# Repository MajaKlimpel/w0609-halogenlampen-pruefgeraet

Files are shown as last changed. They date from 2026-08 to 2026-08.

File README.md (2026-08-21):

# W0609 Halogenlampen-Prüfgerät

Prüfgerät für Lebensdauertests an Halogenlampen mit zehn parallel betriebenen Kanälen.

Entstanden im Rahmen der Bachelorarbeit "Konzeption, Entwicklung und Validierung eines
automatisierten Prüfgeräts zur parallelen Prüfung von Halogenlampen" von Maja Klimpel,
Technische Universität Berlin, Fachgebiet Elektronische Mess- und Diagnosetechnik,
in Zusammenarbeit mit der KNAUER Wissenschaftliche Geräte GmbH, 2026.

## Überblick

Halogenlampen werden bei KNAUER als Lichtquellen in HPLC-Detektoren eingesetzt.
Mit dem entwickelten Prüfgerät können bis zu zehn Lampen gleichzeitig unter definierten
Bedingungen getestet werden. Dazu werden wiederkehrende Schaltzyklen mit Anstiegsrampe,
Haltephase, Abwärtsrampe und Abkühlphase durchgeführt. Während des Tests werden Strom
und Spannung jedes Kanals, sechs Temperaturen und die Lüfterdrehzahlen sekündlich
erfasst und gespeichert. Sinkt der Strom eines Kanals während der Haltephase unter
0,5 A, wird die entsprechende Lampe als ausgefallen erkannt. Der betroffene Kanal wird
daraufhin abgeschaltet und der Ausfall zusammen mit der Zyklusnummer gespeichert.

Das System besteht aus zwei Teilen. Auf einem Teensy 4.1 läuft die Firmware, die die
Ausgangsspannungen regelt, den Testablauf steuert und die Messwerte erfasst. Auf dem
PC läuft eine in Python geschriebene Bedienoberfläche, die das Gerät über USB steuert,
die Messwerte darstellt und als CSV-Datei speichert.

## Inhalt des Repositories

```
Elektronik/
  Altium/                Altium-Projekt der Leiterplatte und Schaltplan als PDF
  Fertigungsdaten/       BOM, Bohrdaten, Gerber und Bestückungsdaten
Konstruktion/
  Konstruktionsdaten/    Einzelteile und Baugruppen der mechanischen Konstruktion
  w0609_step_compressed.stp   Gesamtbaugruppe als STEP-Datei
Software/
  Firmware/
    Gesamtsystem/        Firmware des Prüfgeräts (Teensy 4.1)
    Testprogramme/       Testprogramme zur Inbetriebnahme der Teilfunktionen
    Kommunikationsprotokoll_W0609_v2.0.pdf
  GUI/
    W0609_GUI.py         Quellcode der Bedienoberfläche
    W0609 Halogenlampen-Prüfgerät.exe   ausführbare Windows-Anwendung
    Log/                 aufgezeichnete Messreihen
Datenblaetter und Pruefprotokoll/
  Halogenlampe/          Datenblätter der geprüften Lampen
  Deuteriumlampe/        Datenblatt der Deuteriumlampe
  ASA/                   Werkstoffdatenblätter des verwendeten Filaments
  Prüfprotokoll.pdf      Prüfprotokoll des entwickelten Geräts
```

## Elektronik

Der Ordner `Elektronik/Altium` enthält das vollständige Altium-Projekt der entwickelten
Leiterplatte. Der Schaltplan liegt zusätzlich als PDF vor. Unter
`Elektronik/Fertigungsdaten` befinden sich die zur Fertigung und Bestückung erzeugten
Daten (Stückliste, Gerber- und Bohrdaten sowie Bestückungsdaten).

## Konstruktion

Die mechanische Konstruktion liegt als Gesamtbaugruppe im STEP-Format vor
(`w0609_step_compressed.stp`). Der Ordner `Konstruktionsdaten` enthält zusätzlich die
Einzelteile und Baugruppen des CAD-Modells.

## Firmware

Die Firmware unter `Software/Firmware/Gesamtsystem` steuert das Prüfgerät. Sie regelt
die zehn Ausgangsspannungen, steuert die Lüfter und das Gerätedisplay und führt den
Prüfablauf auch ohne angeschlossenen PC weiter. Die Kommunikation mit der 
Bedienoberfläche erfolgt über USB-Serial mit 115200 Baud. Das verwendete ASCII-Protokoll 
ist in Kommunikationsprotokoll_W0609_v2.0.pdf beschrieben. Die Kalibrierwerte der Kanäle 
liegen im EEPROM des Mikrocontrollers und bleiben damit im Gerät erhalten.

Der Ordner `Testprogramme` enthält kleine, voneinander unabhängige Programme, mit denen
die einzelnen Teilfunktionen der Leiterplatte in Betrieb genommen und geprüft wurden:
Buck-Wandler und Enable-Signale, DAC-Ansteuerung, Temperatursensoren, Strom- und
Spannungsmessung über die Multiplexer, Lüfteransteuerung mit Drehzahlrückmeldung sowie
Display, Taster und Status-LED. Jedes Programm spricht nur die jeweilige Baugruppe an
und gibt die Ergebnisse über die serielle Schnittstelle aus.

## Bedienoberfläche

Die Oberfläche ist in Python mit PyQt5 umgesetzt. Sie bietet die Einstellung der
Prüfspannung von 0 bis 7 V gemeinsam oder je Kanal, die Vorgabe von Rampenzeit,
An-Zeit, Aus-Zeit und Zyklenzahl, Live-Diagramme für Strom, Spannung und Temperatur, 
die Auswertung mehrerer Messreihen nach Ausfällen je Zyklus, einen Assistenten zur 
Kalibrierung der Ausgangsspannung und einen Demo-Modus, der die Oberfläche mit 
simulierten Werten auch ohne angeschlossenes Gerät bedienbar macht.

Für den Betrieb wird die Anwendung `W0609 Halogenlampen-Prüfgerät.exe` im Ordner
`Software/GUI` gestartet, der COM-Port des Geräts ausgewählt und auf Verbinden geklickt.
Nach Eingabe der Testparameter und der Batch-Nummer beginnt der Test. Die Messreihe wird
am Ende automatisch im Ordner `Log` neben der Anwendung gespeichert.

Wer den Quellcode direkt ausführen möchte, benötigt Python 3 mit den Paketen PyQt5,
pyserial, matplotlib und numpy, für die Wärmebilddarstellung zusätzlich scipy:

```
python Software/GUI/W0609_GUI.py
```

## Messdaten

Die Dateien im Ordner `Software/GUI/Log` enthalten die aufgezeichneten Messreihen. Sie
sind mit Semikolon getrennt und verwenden das Komma als Dezimaltrennzeichen. Dadurch 
können sie direkt in Excel geöffnet werden. Am Dateianfang stehen Testdatum und 
Batch-Nummer. Jede weitere Zeile entspricht einer Sekunde Messzeit und enthält 
Zeitstempel, Betriebszustand, Zyklusnummer, Strom und Spannung aller zehn Kanäle, 
die sechs Temperaturen, die Lüfterdrehzahlen und die bis dahin ausgefallenen Kanäle.

## Datenblätter und Prüfprotokoll

Der Ordner enthält die von KNAUER bereitgestellten Datenblätter der 
Halogenlampen und der Deuteriumlampe. Außerdem sind dort die Werkstoffdatenblätter
des für die Konstruktion verwendeten Filaments sowie das Prüfprotokoll des
entwickelten Geräts abgelegt.

## Autorin

Maja Klimpel, 2026

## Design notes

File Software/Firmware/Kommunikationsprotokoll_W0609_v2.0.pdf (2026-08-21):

W0609 Halogenlampen-Pruefgeraet · Serielles Kommunikationsprotokoll · Version 2.0

# Serielles Kommunikationsprotokoll

## W0609 Halogenlampen-Prüfgerät

Dokument | Serielles Kommunikationsprotokoll
Version | 2.0
Stand | 18.08.2026
Gerät | W0609 Halogenlampen-Prüfgerät
Firmware | Gesamtsystem.ino (Teensy 4.1)
Software | W0609_GUI.py (Python-GUI)
Schnittstelle | USB-Serial (CDC), 115200 Baud
Autorin | Maja Klimpel

Dieses Dokument beschreibt die serielle Schnittstelle zwischen dem Mikrocontroller Teensy 4.1 (Firmware) und einer übergeordneten Steuersoftware (Python-GUI): Verbindungsparameter, Befehlssatz, Antwortformate, Zustandsautomaten sowie typische Abläufe.

Hinweis zur Erstellung: Dieses Dokument wurde mit Unterstützung des KI-Assistenten Claude (Anthropic) auf Basis der Firmware (Gesamtsystem.ino) und der GUI (W0609_GUI.py) erstellt. Alle Inhalte wurden von der Autorin geprüft und werden von ihr verantwortet.

## Inhalt

W0609 Halogenlampen-Prüfgerät | Serielles Kommunikationsprotokoll · V2.0
Stand: 18.08.2026 | Seite 2

## 1 Verbindung

Parameter | Wert
Schnittstelle | USB-Serial (CDC)
Baudrate | 115200 (8N1)
Zeilenende | \n (LF); \r wird ignoriert
Kodierung | ASCII

Hinweis: Beim Teensy ist Serial USB-CDC — die Baudrate wird hardwareseitig ignoriert (volle USB-Geschwindigkeit). 115200 ist als Konvention gesetzt; die GUI öffnet mit 115200.

## 2 Grundprinzip

Befehle gehen zeilenweise von der GUI an den Teensy; Groß-/Kleinschreibung ist unerheblich. Antworten des Teensy sind am Zeilenanfang (Präfix) unterscheidbar:

Präfix | Bedeutung
OK … | Befehl akzeptiert
ERR … | Fehler / ungültiger Befehl
DATA … | periodische oder angeforderte Messdaten
EVENT … | asynchrones Ereignis
CFG … | Konfigurationsausgabe (Antwort auf GETCFG)
CAL … | Kalibrierdaten (Antwort auf CALGET)
sonstige | informative Zeilen (z. B. Antwort auf PING, HELP)

Nach dem Reset sendet der Teensy:

W0609 Halogenlampentest bereit. 'HELP' fuer Befehle.

## 3 Befehle

### 3.1 Steuerung

Befehl | Beschreibung | Antwort
START | Test starten (Zyklen lt. Konfiguration) | OK START / ERR running
STOP | Test/Ausgänge stoppen, zurück in Ruhe | OK STOP
MODE EVAL | MODE REAL | Zeit-Presets laden | OK MODE EVAL/REAL
EVAL / REAL | Kurzform von MODE … | OK MODE EVAL/REAL
SETV <ch> <v> | Kanal ch (1–10) auf v Volt (0–7), geregelt + kalibriert | OK SETV ch v
<ch>,<v> | Kurzform von SETV (z. B. 3,5.0) | OK SETV ch v
OFF <ch> | Kanal ch ausschalten | OK SETV ch 0
ALL <v> | alle Kanäle auf v Volt (geregelt) | Alle Kanaele auf … V
OFFALL | alle Kanäle aus | Alle Kanaele auf 0 V
SETV/OFF/ALL sind nur erlaubt, wenn kein Test läuft (sonst ERR test running).

### 3.2 Konfiguration

Befehl | Beschreibung | Antwort
RAMP <s> | Rampendauer hoch = runter, in Sekunden | OK RAMP <ms>
ONTIME <s> | Haltezeit bei Vollspannung, Sekunden | OK ONTIME <ms>
OFFTIME <s> | Abkühlzeit (0 V), Sekunden | OK OFFTIME <ms>
CYCLES <n> | Zyklenanzahl (1–99) | OK CYCLES <n>
TESTV <v> | Test-Sollspannung (0–7 V) für alle Kanäle; überschreibt zuvor gesetzte Einzelwerte | OK TESTV <v>
TESTVCH <ch> <v> | Test-Sollspannung (0–7 V) nur für Kanal ch — je Kanal individuell einstellbar | OK TESTVCH <ch> <v>
GETCFG | aktuelle Konfiguration ausgeben | CFG … (Abschnitt 4.2)

### 3.3 Auslesen / Datenstrom

Befehl | Beschreibung | Antwort
GETI <ch> | Strom Kanal ch [A] | I<ch>=<wert>
GETU <ch> | Spannung Kanal ch [V] | U<ch>=<wert>
GETT <n> | Temperatur Sensor n (1–6) [°C] | T<n>=<wert>
GETALL | komplette Messzeile sofort | DATA …
STREAM <ms> | Auto-Datenstrom alle <ms> ms (min. 100) | OK STREAM <ms>
STREAM OFF | Auto-Datenstrom aus | OK STREAM OFF
Standard nach Reset: Stream an, alle 1000 ms. Die GUI schaltet beim Verbinden auf 100 ms um (STREAM 100). Die GET…-Werte stammen aus der jeweils letzten Messung (im STREAM-Intervall aktualisiert).

### 3.4 Kalibrierung der Ausgangsspannung

Feinkalibrierung je Kanal als Korrekturgerade Vkorr = m · Vsoll + b (Standard: m = 1, b = 0). Die GUI enthält dafür ein eigenes Kalibrier-Werkzeug (Service-Bereich).

Befehl | Beschreibung | Antwort
CALOUT <v> | alle Kanäle open-loop auf v Volt mit roher Vorsteuerung (ohne Feinkalibrierung, Regelung aus) — Zustand zum Nachmessen mit dem Multimeter | OK CALOUT <v>
CALSET <ch> <m> <b> | Korrekturgerade für Kanal ch setzen | OK CALSET <ch> <m> <b>
CALGET | Korrekturwerte aller Kanäle ausgeben | CAL M=… B=…
CALRESET | alle Korrekturen auf m = 1, b = 0 zurücksetzen | OK CALRESET
CALSAVE | Korrekturen dauerhaft im EEPROM speichern | OK CALSAVE

### 3.5 Service / Abgleich

Befehl | Beschreibung
DAC <ch> <vdac> | DAC eines Kanals direkt setzen (0–5 V), open-loop — zum Abgleich
SETALL <v> | alle Kanäle open-loop auf v mit kalibrierter Vorsteuerung (Regelung aus)

Befehl | Beschreibung
RAW | rohe (unkalibrierte) Spannungsmesswerte aller Kanäle
PING / ID | Identifikation: W0609 Halogenlampentest Teensy4.1
HELP | Befehlsübersicht

### 3.6 Anzeige (Gerätedisplay)

Befehl | Beschreibung | Antwort
GUI 1 | Display zeigt „PC-Steuerung aktiv“ (GUI verbunden) | OK GUI 1
GUI 0 | Display zurück auf Standard-Startbildschirm | OK GUI 0
Die GUI sendet GUI 1 beim Verbinden und GUI 0 beim Trennen.

## 4 Antwort-Formate

### 4.1 DATA — Messdatenzeile

DATA t=<ms> state=<S> cyc=<c>/<N> I=<i1..i10> U=<u1..u10> T=<t1..t6> rpmR=<r> rpmL=<l> def=<liste>

Feld | Bedeutung
t | Millisekunden seit Reset (millis())
state | IDLE | RUNNING | DONE | CALIBRATION
cyc | abgeschlossene Zyklen / Gesamtzahl
I | 10 Ströme [A], kommagetrennt, 3 Nachkommastellen
U | 10 Spannungen [V], kommagetrennt, 3 Nachkommastellen; abgeschaltete Kanäle melden exakt 0.000
T | 6 Temperaturen [°C], kommagetrennt, 2 Nachkommastellen
rpmR / rpmL | Lüfterdrehzahl rechts / links [U/min]
def | Liste defekter Kanäle (z. B. 7,9), - wenn keine

Beispiel:

DATA t=42310 state=RUNNING cyc=2/10 I=0.85,0.84,0.86,0.00,0.85,0.85,0.84,0.85,0.86,0.85 U=5.001,4.998,5.002,0.000,5.000,4.999,5.001,5.000,4.998,5.002 T=24.31,24.50,23.98,24.12,24.44,24.06 rpmR=1450 rpmL=1460 def=4
(tatsächlich eine einzige Zeile; hier zur Lesbarkeit umbrochen)

### 4.2 CFG — Konfiguration

CFG mode=REAL ramp_s=60.0 on_s=1800.0 off_s=900.0 cycles=10 testv=5.00 channels=10 sensors=6 reg=1 stream_ms=1000 streamon=1
testv ist die zuletzt global gesetzte Sollspannung; individuelle Werte je Kanal (TESTVCH) erscheinen hier nicht.

### 4.3 CAL — Kalibrierdaten (Antwort auf CALGET)

CAL M=<m1>,…,<m10> B=<b1>,…,<b10>
Je 10 Werte (5 Nachkommastellen): Steigung m und Offset b der Korrekturgeraden pro Kanal.

### 4.4 EVENT — Ereignisse

Ereignis | Bedeutung
EVENT DEFECT <ch> | Kanal ch als defekt erkannt (Strom < 0,5 A im Haltepunkt). Der Kanal wird mit Rampe heruntergefahren und für den Rest des Tests stillgelegt.
EVENT TESTDONE | alle Zyklen aller Kanäle abgeschlossen

## 5 Zustände (Firmware)

Automat | Zustände
Test (state) | IDLE -> RUNNING -> DONE; CALIBRATION im manuellen/Kalibrier-Modus (SETALL/CALOUT)
Pro Kanal (intern) | WAIT_START -> RAMP_UP -> HOLD -> RAMP_DOWN -> OFF -> (nächster Zyklus) -> DONE
Display | LOGO (3 s) -> START -> TEST; bei GUI 1 Anzeige „PC-Steuerung aktiv“

Ein Zyklus = Rampe hoch -> Halten (Vollspannung) -> Rampe runter -> Abkühlen (0 V). Die Kanäle starten mit 1 s Zeitversatz (Lastspitzen-Vermeidung) und sind gleich lang an. In Abkühlphasen läuft der Lüfter mit mindestens 30 %.

### 5.1 Preset-Zeiten

Modus | Rampe | An | Aus
REAL (Standard) | 60 s | 1800 s (30 min) | 900 s (15 min)
EVAL | 2 s | 5 s | 2 s

## 6 Typische Abläufe

Überwachter Testlauf (so arbeitet die GUI)

PING | -> W0609 Halogenlampentest Teensy4.1
GUI 1 | -> OK GUI 1
STREAM 100 | -> OK STREAM 100
RAMP 60 | -> OK RAMP 60000
ONTIME 1800 | -> OK ONTIME 1800000
OFFTIME 900 | -> OK OFFTIME 900000
CYCLES 10 | -> OK CYCLES 10
TESTVCH 1 5.00 | -> OK TESTVCH 1 5.000 | (je Kanal)
START | -> OK START
... laufend: DATA ... , ggf. EVENT DEFECT x ... am Ende: EVENT TESTDONE

Einzelnen Kanal manuell prüfen

SETV 3 5.0 | -> OK SETV 3 5.000
GETU 3 | -> U3=5.001
GETI 3 | -> I3=0.850
OFF 3 | -> OK SETV 3 0.000

Ausgangsspannung kalibrieren (GUI-Kalibrier-Werkzeug)

CALOUT 5.00 | -> OK CALOUT 5.000 | (alle Kanaele roh auf 5 V)
... je Kanal mit Multimeter messen, GUI berechnet m/b ...
CALSET 1 1.01234 -0.03210 -> OK CALSET 1 1.01234 -0.03210
CALSAVE | -> OK CALSAVE | (dauerhaft im EEPROM)
STOP | -> OK STOP

## 7 Hinweise für die GUI-Implementierung

- Zeilen mit unbekanntem Präfix tolerant ignorieren (Vorwärtskompatibilität: es können später Felder/Events dazukommen).
- DATA nach Leerzeichen splitten, dann je Token an = trennen; Arrays an , trennen.
- Spannung bis 7 V einstellbar. Der Abgleich der Vorsteuerung erfolgte bei 5 V; oberhalb zieht die Closed-Loop-Regelung nach (Messbereich bis 7 V).
- Loggen: DATA-Zeilen mit Zeitstempel direkt als CSV ablegen (ein Datensatz/Zeile).
- Beim Trennen GUI 0 senden, damit das Gerät wieder den Startbildschirm zeigt.

## 8 Änderungshistorie

Version | Datum | Änderungen
1.0 | 26.06.2026 | Erstfassung
2.0 | 18.08.2026 | Neu: TESTVCH (Sollspannung je Kanal); Kalibrierbefehle CALOUT, CALSET, CALGET, CALRESET, CALSAVE; Display-Umschaltung GUI 0/1; Antwortpräfix CAL. Zustand HOLD heißt jetzt CALIBRATION. TESTV setzt alle Kanalwerte. Abgeschaltete Kanäle melden in DATA exakt 0,000 V. Defekte Kanäle werden mit Rampe heruntergefahren und stillgelegt. GUI-Datenstrom 100 ms dokumentiert.

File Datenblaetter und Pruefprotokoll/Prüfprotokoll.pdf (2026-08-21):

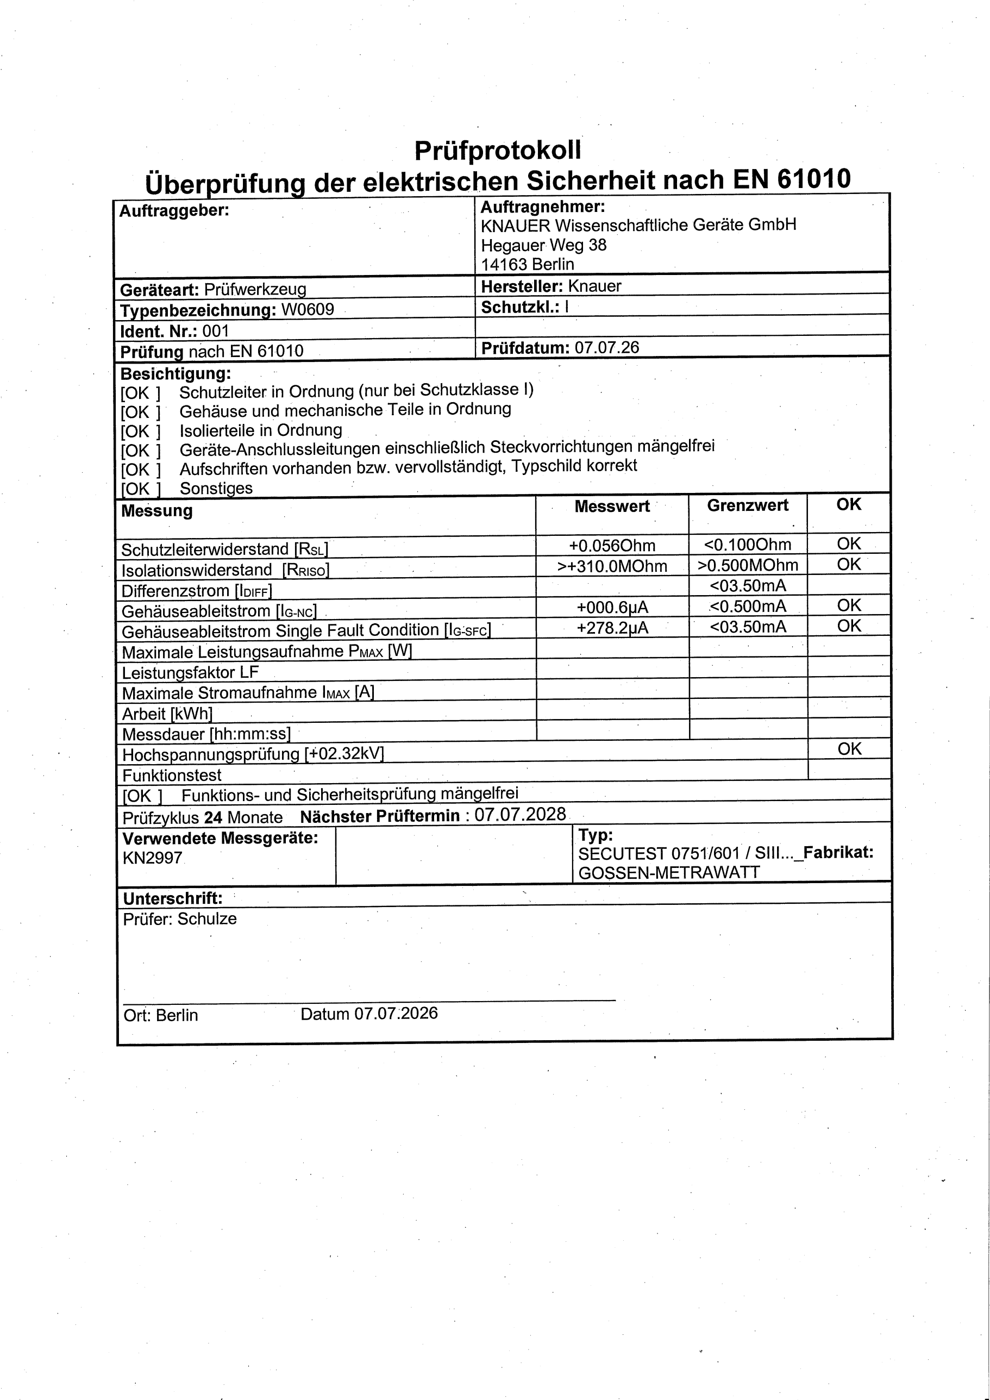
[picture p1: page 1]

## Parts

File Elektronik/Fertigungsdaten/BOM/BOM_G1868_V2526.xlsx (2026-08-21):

Stückliste G1868 V25/26
Baugruppe |  | G1868
Version |  | V25/26
Projekt |  | Halogenlampenprüfplatz
Name |  | Datum
Klimpel |  | 19.06.2026 | Bearbeitet
Hemmer |  | 2026-06-20 | Geprüft
Pos. | Stk. | Referenz | Hersteller | Art.-Nr. | Beschreibung
1 | 1 | V25/26 |  |  | Leiterplatte V25/26, FR4 UL94 V0
2 | 69 | C1, C2, C3, C6, C7, C11, C16, C18, C19, C23, C25, C27, C28, C29, C30, C31, C32, C33, C40, C43, C44, C45, C46, C47, C48, C49, C50, C51, C52, C53, C63, C65, C67, C69, C70, C71, C72, C73, C74, C75, C76, C77, C78, C79, C80, C90, C91, C92, C96, C97, C98, C99, C100, C101, C102, C103, C108, C109, C110, C111, C112, C113, C114, C115, C116, C129, C130, C131, C132 |  |  | MLCC 100 nF, 0402, 50 V, 10 %, X7R
3 | 2 | C4, C5 |  |  | MLCC 1 nF, 0402, 50 V, 10 %, X7R
4 | 24 | C8, C9, C13, C14, C20, C21, C34, C35, C36, C37, C54, C55, C56, C57, C58, C59, C81, C82, C83, C84, C85, C86, C104, C105 |  |  | MLCC 22 µF, 0805, 25 V, 20 %, X5R
5 | 13 | C10, C15, C22, C26, C41, C42, C64, C66, C68, C93, C94, C95, C107 |  |  | MLCC 10 µF, 0805, 25 V, 10 %, X7R
6 | 12 | C12, C17, C24, C38, C39, C60, C61, C62, C87, C88, C89, C106 |  |  | MLCC 22 pF, 0402, 25 V, 10 %, C0G
7 | 2 | C117, C118 |  |  | MLCC 10 nF, 0402, 50 V, 10 %, X7R
8 | 10 | C119, C120, C121, C122, C123, C124, C125, C126, C127, C128 | Wurth Elektronik | 875115557005 | WCAP-PSHP Aluminum Polymer Capacitors, 150uF, 25V
9 | 10 | D1, D2, D3, D4, D5, D6, D7, D8, D9, D10 | Vishay | BAT54W-HG3-08 | Diode Small Signal Schottky 30V 0.2A 2-Pin SOD-123 T/R Automotive AEC-Q101
10 | 1 | IC1 | PJRC, Würth | Teensy 4.1, 2x61302411821 | MCU
11 | 2 | IC2, IC3 | Texas Instruments | SN74LV1T08DCKR | Single power supply 2-input POSITIVE AND Gate with Logic Level Shifter 5-SC70 -40 to 125
12 | 12 | IC4, IC5, IC7, IC13, IC14, IC20, IC21, IC22, IC29, IC30, IC31, IC37 | Texas Instruments | TPSM863252RDXR | 3-V to 17-V input voltage, 3-A Eco-mode synchronous buck module
13 | 10 | IC6, IC11, IC12, IC17, IC18, IC19, IC26, IC27, IC28, IC36 | Texas Instruments | INA190A1IDCKR | Precision Current-Sense Amplifier Bi-Directional 1-Channel 200V/V 1.7V to 5.5V 6-Pin SC-70 T/R
14 | 10 | IC8, IC15, IC16, IC23, IC24, IC25, IC32, IC33, IC34, IC38 | Texas Instruments | TLV9001TIDCKR | Operational Amplifier Single 2V/us 1.8V to 5.5V 5-Pin SC-70 T/R
15 | 2 | IC9, IC35 | Texas Instruments | CD74HC4067SM96 | 5V, 16: 1, 1-channel, analog multiplexer 24-SSOP -55 to 125
16 | 1 | IC10 | Analog Devices | AD5673RBCPZ-2 | 16-Channel, 16-Bit nanoDAC+ with 2 ppm/°C Voltage Reference TC, I2C Interface
17 | 6 | IC39, IC40, IC41, IC42, IC43, IC44 | Texas Instruments | TMP1075DSGR | IC TEMP SENSOR / Temperature Sensor Digital, Local -55°C ~ 125°C 12 b 8-WSON (2x2)
18 | 20 | MP1, MP2, MP3, MP4, MP5, MP6, MP7, MP8, MP9, MP10, MP11, MP12, MP13, MP14, MP15, MP16, MP17, MP18, MP19, MP20 | PEM | SMTSO-M3-10ET | Fixed Resistor, Wire Wound, 2W, 6.8ohm, 300V, 5% +/-Tol, -200, 200ppm/Cel, Surface Mount, 2616
19 | 4 | R1, R2, R88, R98 |  |  | Resistor 1 kOhm, 0402, 1 %, TK100, 63 mW
20 | 2 | R3, R4 |  |  | Resistor 100 Ohm, 0402, 1 %, TK100, 63 mW
21 | 1 | R5 |  |  | Resistor 100 kOhm, 0402, 1 %, TK100, 63 mW
22 | 2 | R6, R11 |  |  | Resistor 30 kOhm, 0402, 1 %, TK100, 63 mW
23 | 1 | R7 |  |  | Resistor 45.3 kOhm, 0402, 0.1 %, TK25, 63 mW
24 | 47 | R8, R9, R10, R13, R14, R15, R19, R22, R24, R26, R27, R28, R32, R33, R34, R35, R42, R43, R44, R45, R48, R49, R53, R54, R55, R56, R57, R58, R68, R69, R71, R73, R77, R78, R79, R83, R84, R85, R99, R101, R103, R107, R108, R109, R111, R117, R119 |  |  | Resistor 10 kOhm, 0402, 1 %, TK100, 63 mW
25 | 1 | R12 |  |  | Resistor 75 kOhm, 0402, 1 %, TK100, 63 mW
26 | 1 | R16 |  |  | Resistor 499 Ohm, 0603, 1 %, TK100, 100 mW
27 | 2 | R17, R18 |  |  | Resistor 270 Ohm, 0603, 1 %, TK100, 100 mW
28 | 10 | R20, R30, R31, R50, R51, R52, R80, R81, R82, R110 |  |  | Resistor 75 mOhm, 0805, 1 %, TK50, 750 mW
29 | 10 | R21, R36, R38, R59, R61, R63, R89, R91, R93, R113 |  |  | Resistor 93.1 kOhm, 0402, 0.1 %, TK25, 63 mW
30 | 10 | R23, R37, R39, R60, R62, R64, R90, R92, R94, R114 |  |  | Resistor 11.3 kOhm, 0402, 1 %, TK100, 63 mW
31 | 10 | R25, R40, R41, R65, R66, R67, R95, R96, R97, R115 |  |  | Resistor 64.9 kOhm, 0402, 0.1 %, TK25, 63 mW
32 | 10 | R29, R46, R47, R74, R75, R76, R104, R105, R106, R118 |  |  | Resistor 1.6 kOhm, 0402, 0.1 %, TK25, 63 mW
33 | 4 | R70, R72, R86, R87 |  |  | Resistor 4.7 kOhm, 0402, 1 %, TK100, 63 mW
34 | 2 | ST1, ST3 | Molex | 47053-1000 | KK 254 Vertical Header, with Friction Lock, 4 Circuits, PC Tail Length 3.50mm, Bag
35 | 1 | ST2 | Wurth Elektronik | 68611614122 | Ffc / Fpc Board Connector, Zif, Surface Mount, Plug, 16, Bottom, 1 Mm Rohs Compliant: Yes
36 | 1 | ST4 | JST Commercial | B4P-VH-B(LF)(SN) | Locking Header, Top Entry Type of PBT, 4 Circuit, 3.96mmPitch
37 | 1 | ST5 |  |  | Board Connector, 7 Contact(s), 1 Row(s), Male, Straight, Surface Mount Terminal
38 | 10 | ST6, ST7, ST8, ST9, ST10, ST11, ST12, ST13, ST14, ST15 | WAGO | 2601-3102 | PCB terminal block, lever 1.5 mm² Pin spacing 3.5 mm 2-pole; gray
39 | 3 | T1, T2, T3 | onsemi | BSS138 | Trans MOSFET N Channel 50 Volt 0.22A 3-Pin SOT-23 Tape and Reel
40 | 59 | TP1, TP2, TP3, TP4, TP5, TP6, TP7, TP8, TP9, TP10, TP11, TP12, TP13, TP14, TP15, TP16, TP17, TP18, TP19, TP20, TP21, TP22, TP23, TP24, TP25, TP26, TP27, TP28, TP29, TP30, TP31, TP32, TP33, TP34, TP35, TP36, TP37, TP38, TP39, TP40, TP41, TP42, TP43, TP44, TP45, TP46, TP47, TP48, TP49, TP50, TP59, TP60, TP61, TP62, TP63, TP65, TP66, TP67, TP68 | Harwin | S2761-46R | Test Terminal for Standard Test Probes, Micro Test Lead Clips and Hooks Brass T/R
41 | 9 | TP51, TP52, TP53, TP55, TP56, TP57, TP58, TP64, TP70 | Keystone Electronics | 5011 | Test Point, Multipurpose, Thm, .445 L, .125 Od, Heat Resistant Nylon 46, Black
 | Name |  | Datum | Änderung
1 | Klimpel |  | 19.06.2026 | Musterfreigabe
2
3
4
5
6
7
8
9
10

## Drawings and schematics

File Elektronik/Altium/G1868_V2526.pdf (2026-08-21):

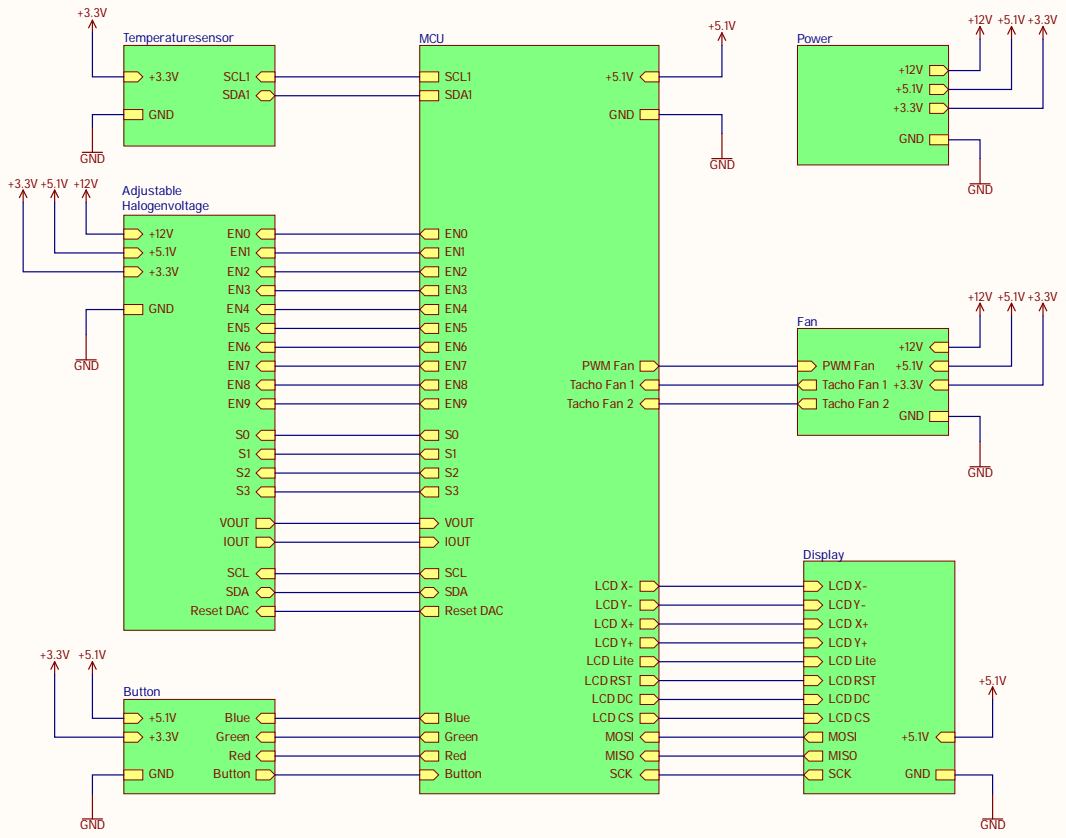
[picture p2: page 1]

Änderung | Datum | Name
Musterfreigabe | 19.06.2026 | Klimpel

Übersicht

Baugruppe | G1868
Projekt | Halogenlampenprüfplatz
Version | V25/26

Name | Datum

Bearbeitet | Klimpel | 19.06.2026
Geprüft

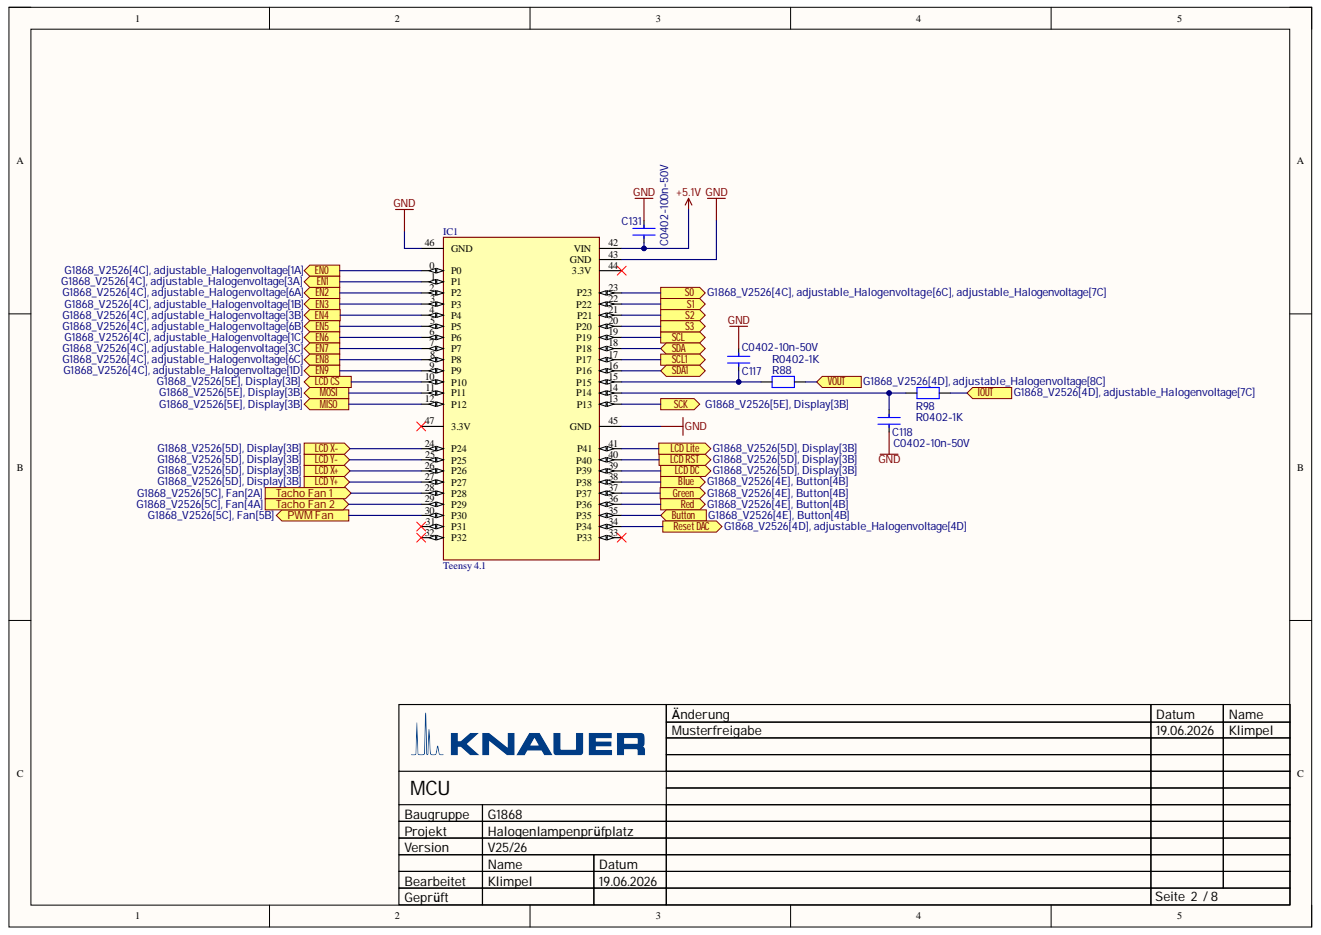
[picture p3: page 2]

Ä nderu n g | Da tu m | N ame
Musterfreigabe | 19.06.2026 | Klimpel

MCU

B a ugruppe | G1868
Projek t | Halogenlampenpr ü fpla tz

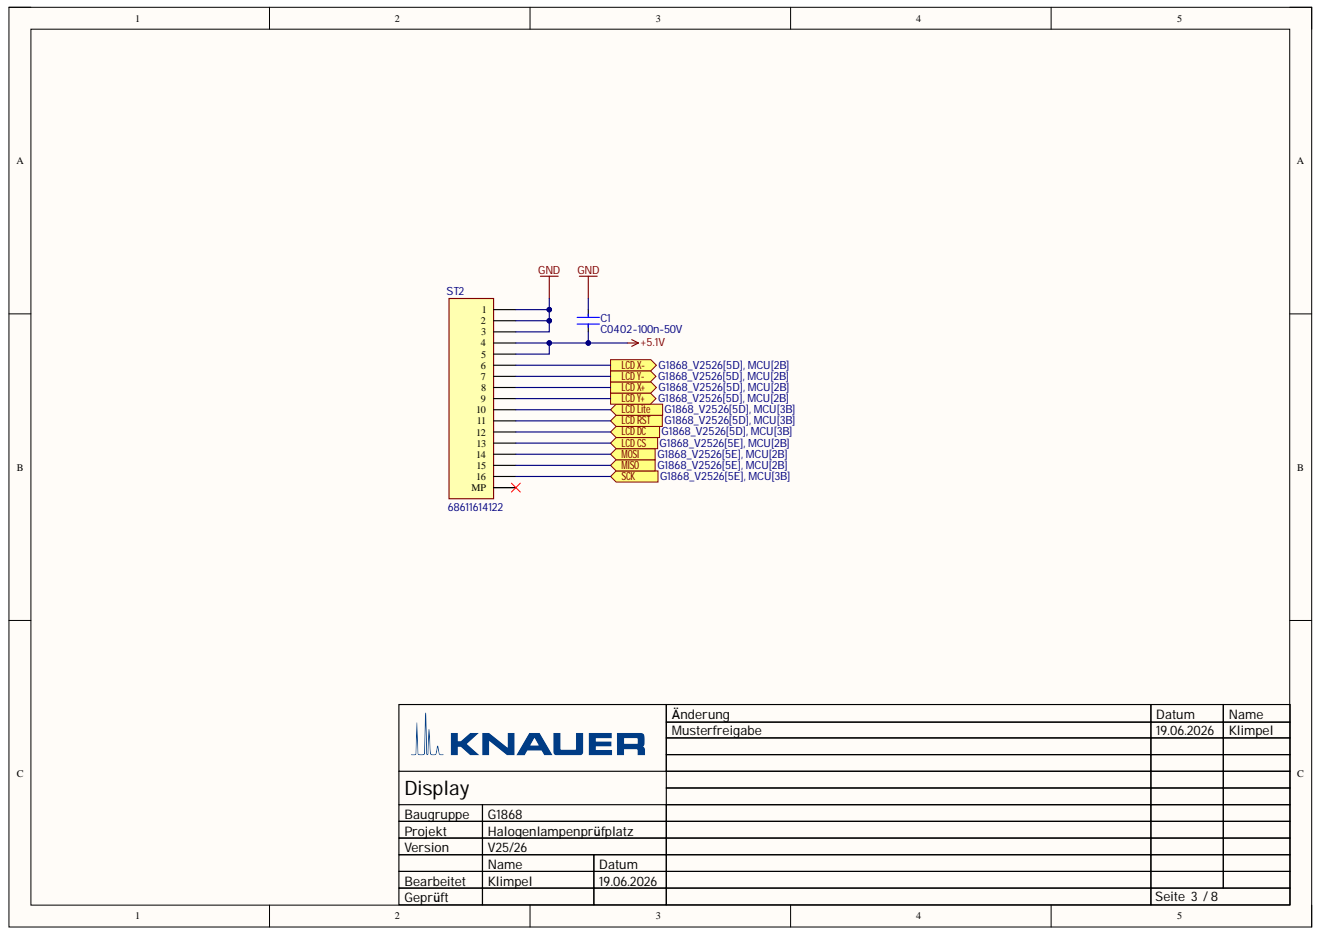
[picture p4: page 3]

Ä nderu n g | Da tu m | N ame
Musterfreigabe | 19.06.2026 | Klimpel

Displa y

B a ugruppe | G1868
Projek t | Halogenlampenpr ü fpla tz

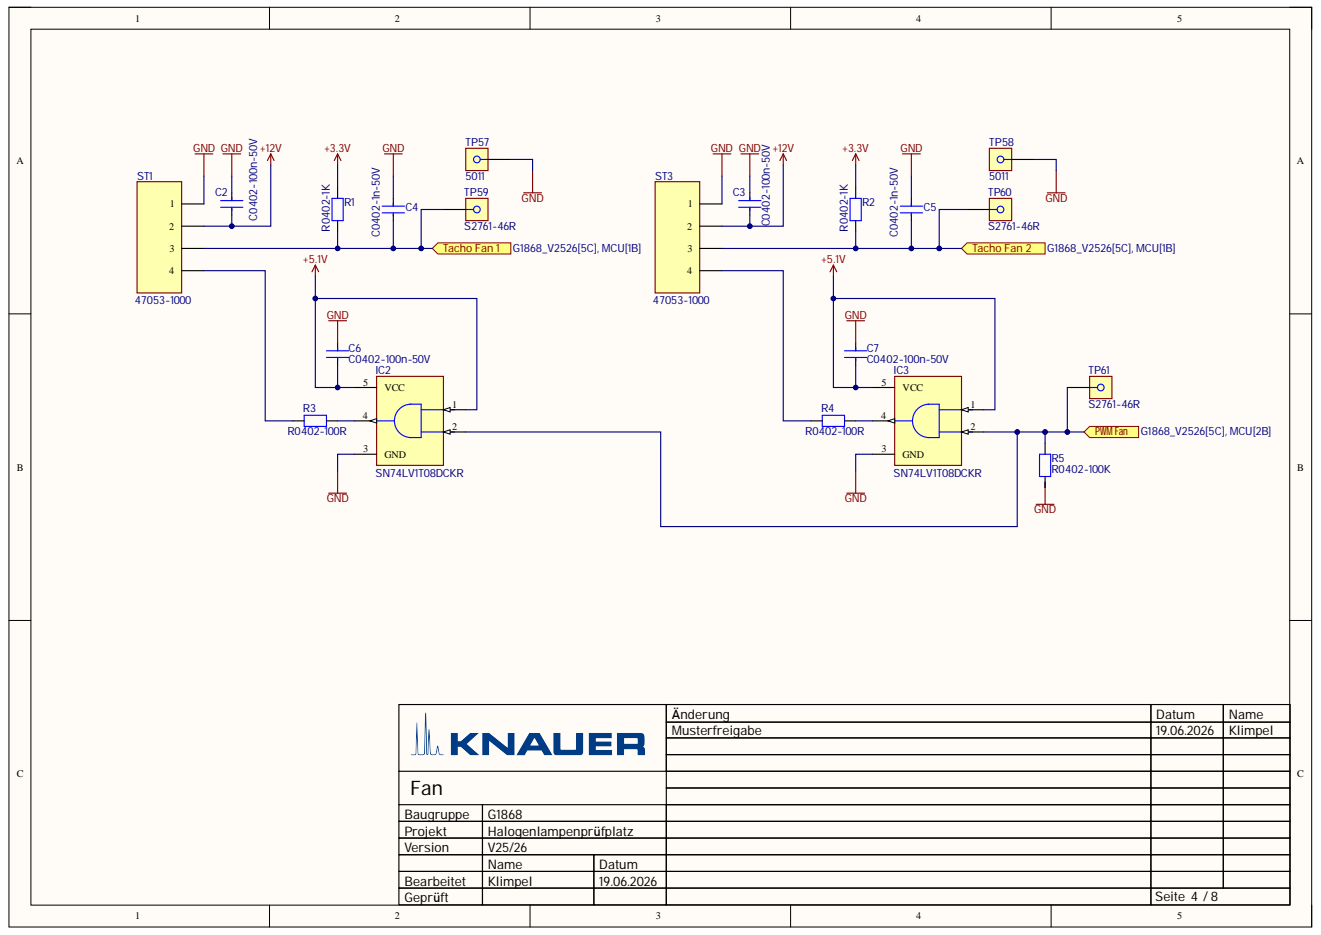
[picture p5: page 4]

Änderung | Datum | Name
Musterfreigabe | 19.06.2026 | Klimpel

Fan

Baugruppe | G1868
Projekt | Halogenlampenprüfplatz
Version | V25/26

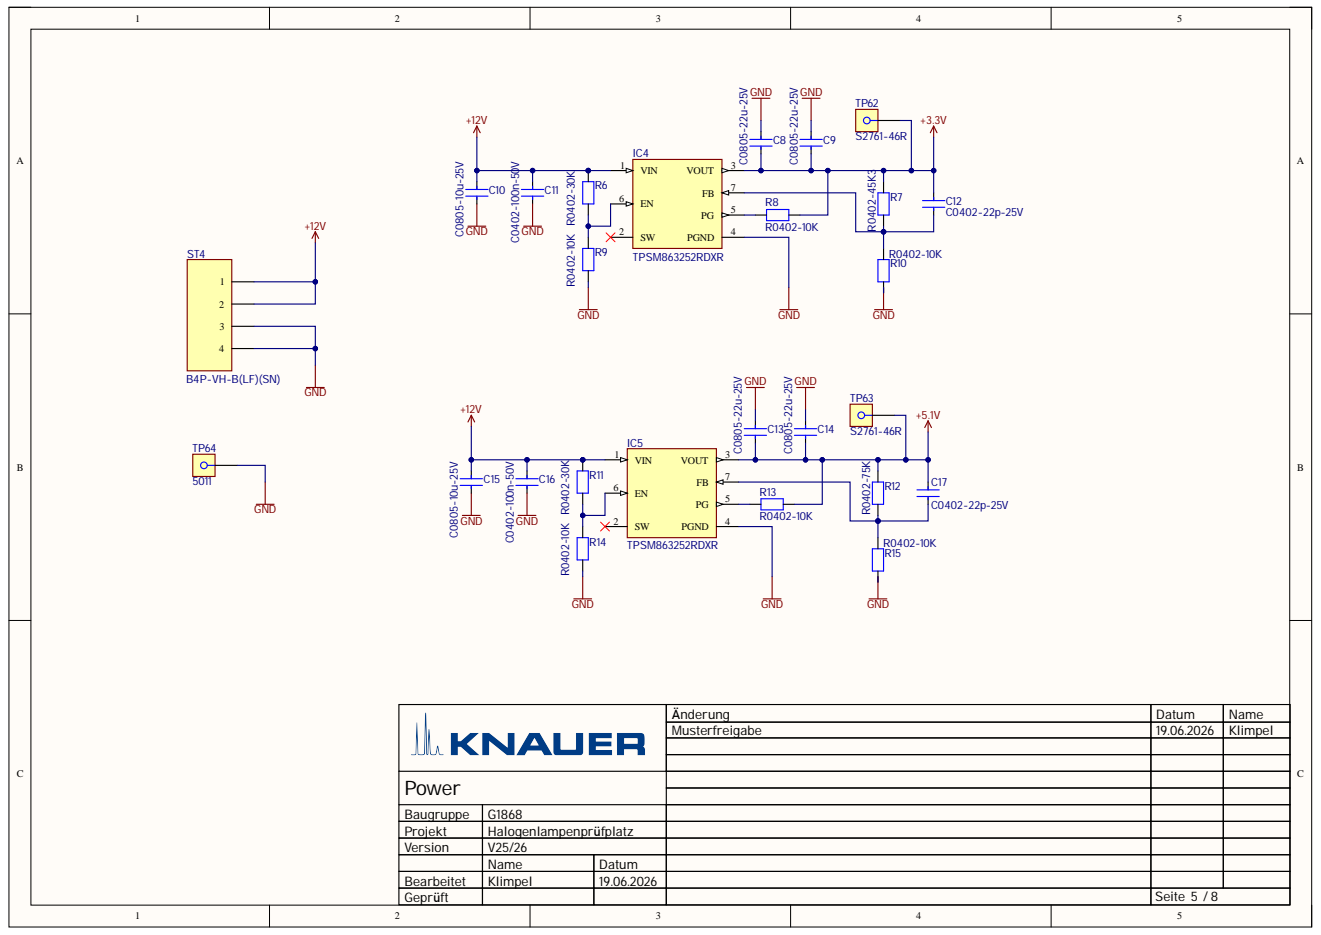
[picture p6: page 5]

Ä nderu n g | Da tu m | N ame
Musterfreigabe | 19.06.2026 | Klimpel

Power

B a ugruppe | G1868
Projek t | Halogenlampenpr ü fpla tz

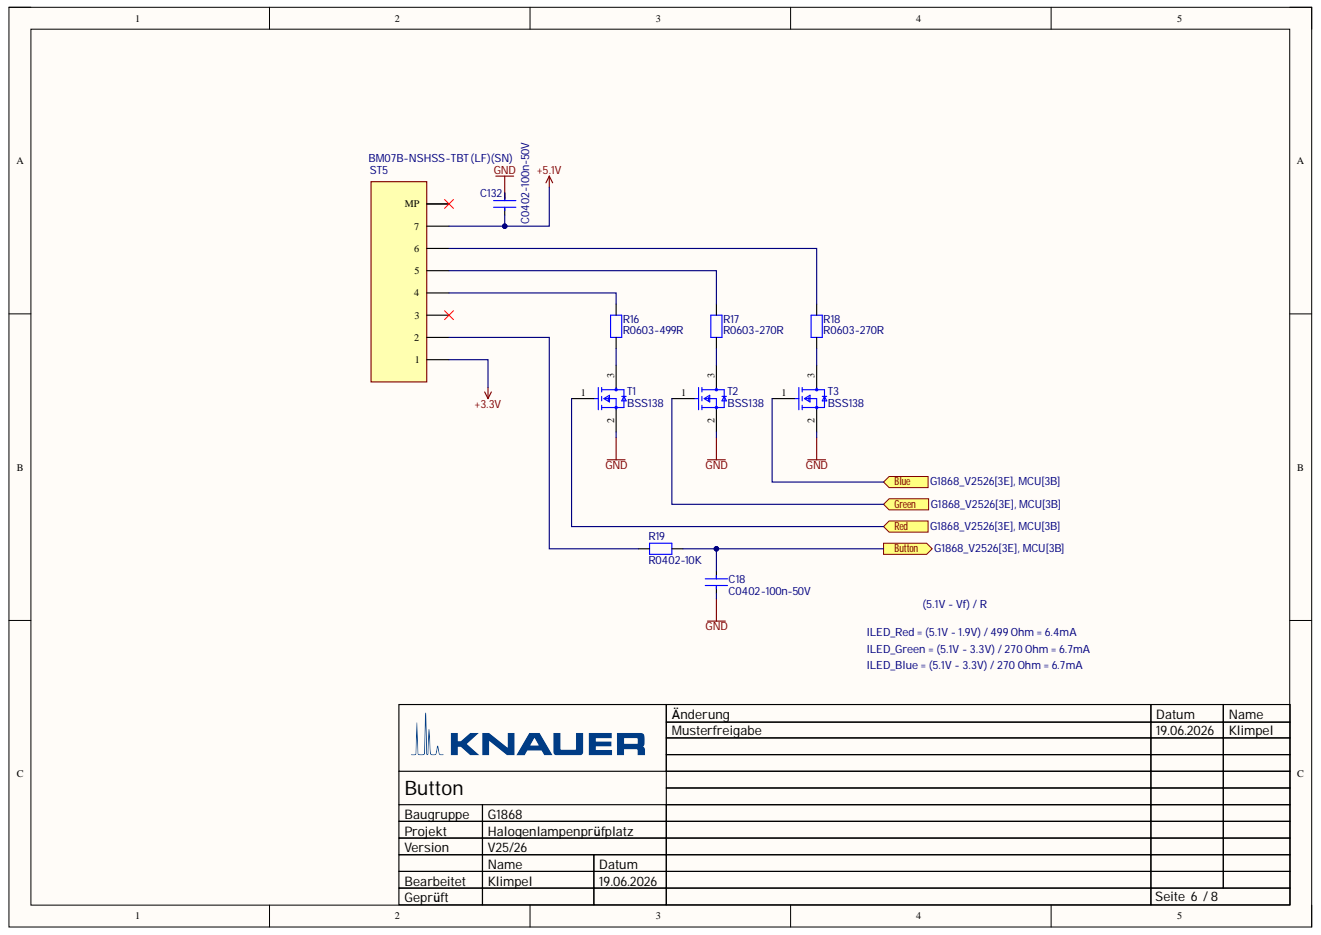
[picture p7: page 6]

BM07B-NSHSS-TBT (LF)(SN)

Änderung | Datum | Name
Musterfreigabe | 19.06.2026 | Klimpel

Button

Baugruppe | G1868
Projekt | Halogenlampenprüfplatz
Version | V25/26

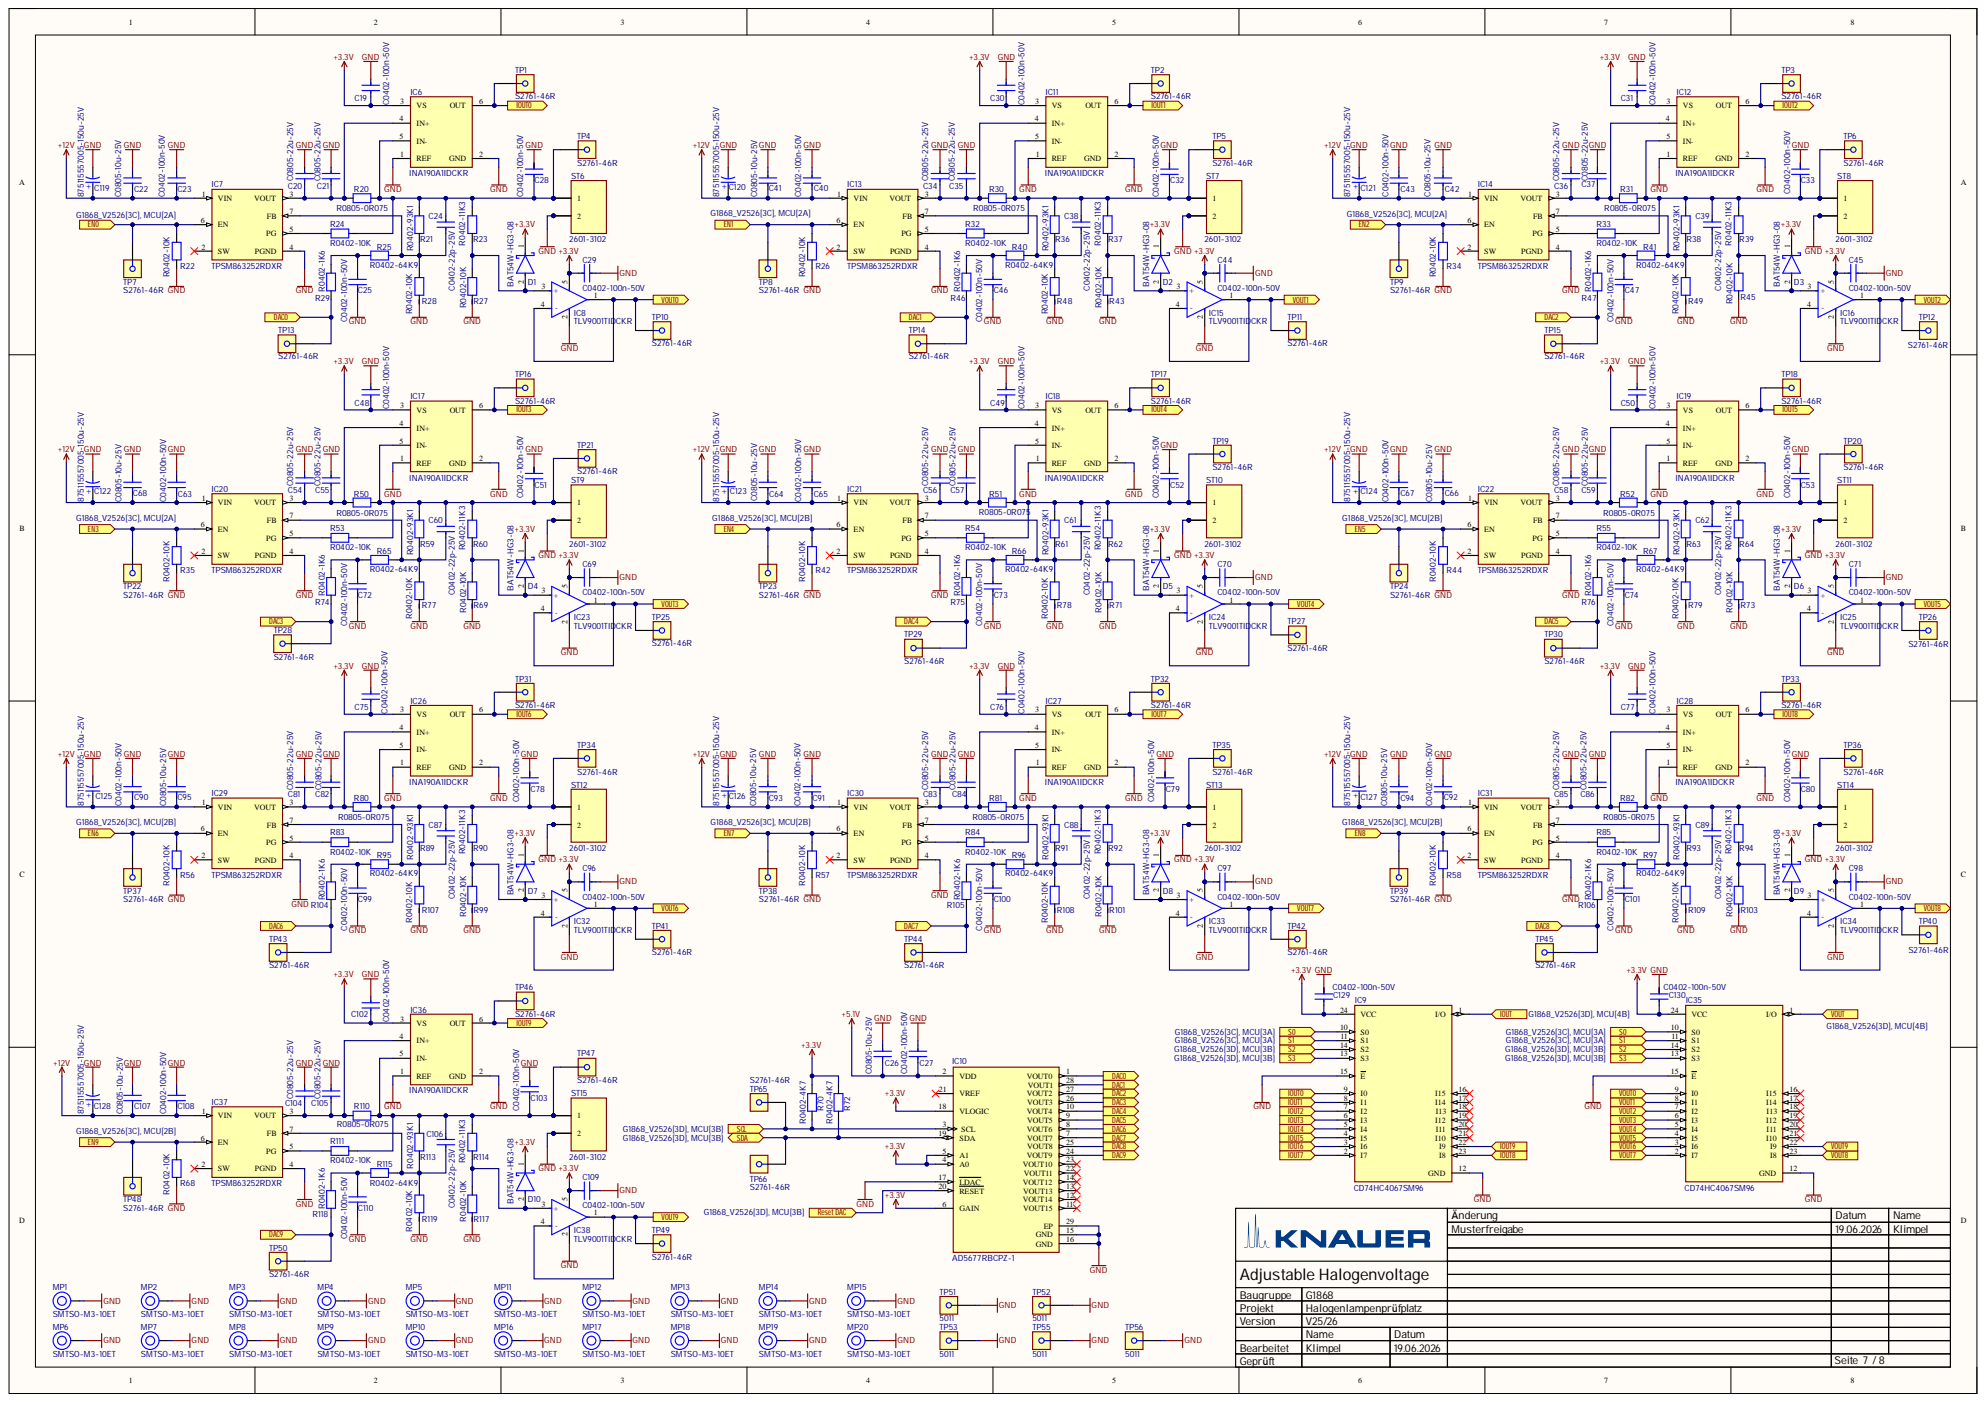
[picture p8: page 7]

Baugruppe | G1868
Projekt | Halogenlampenprüfplatz
Version | V25/26

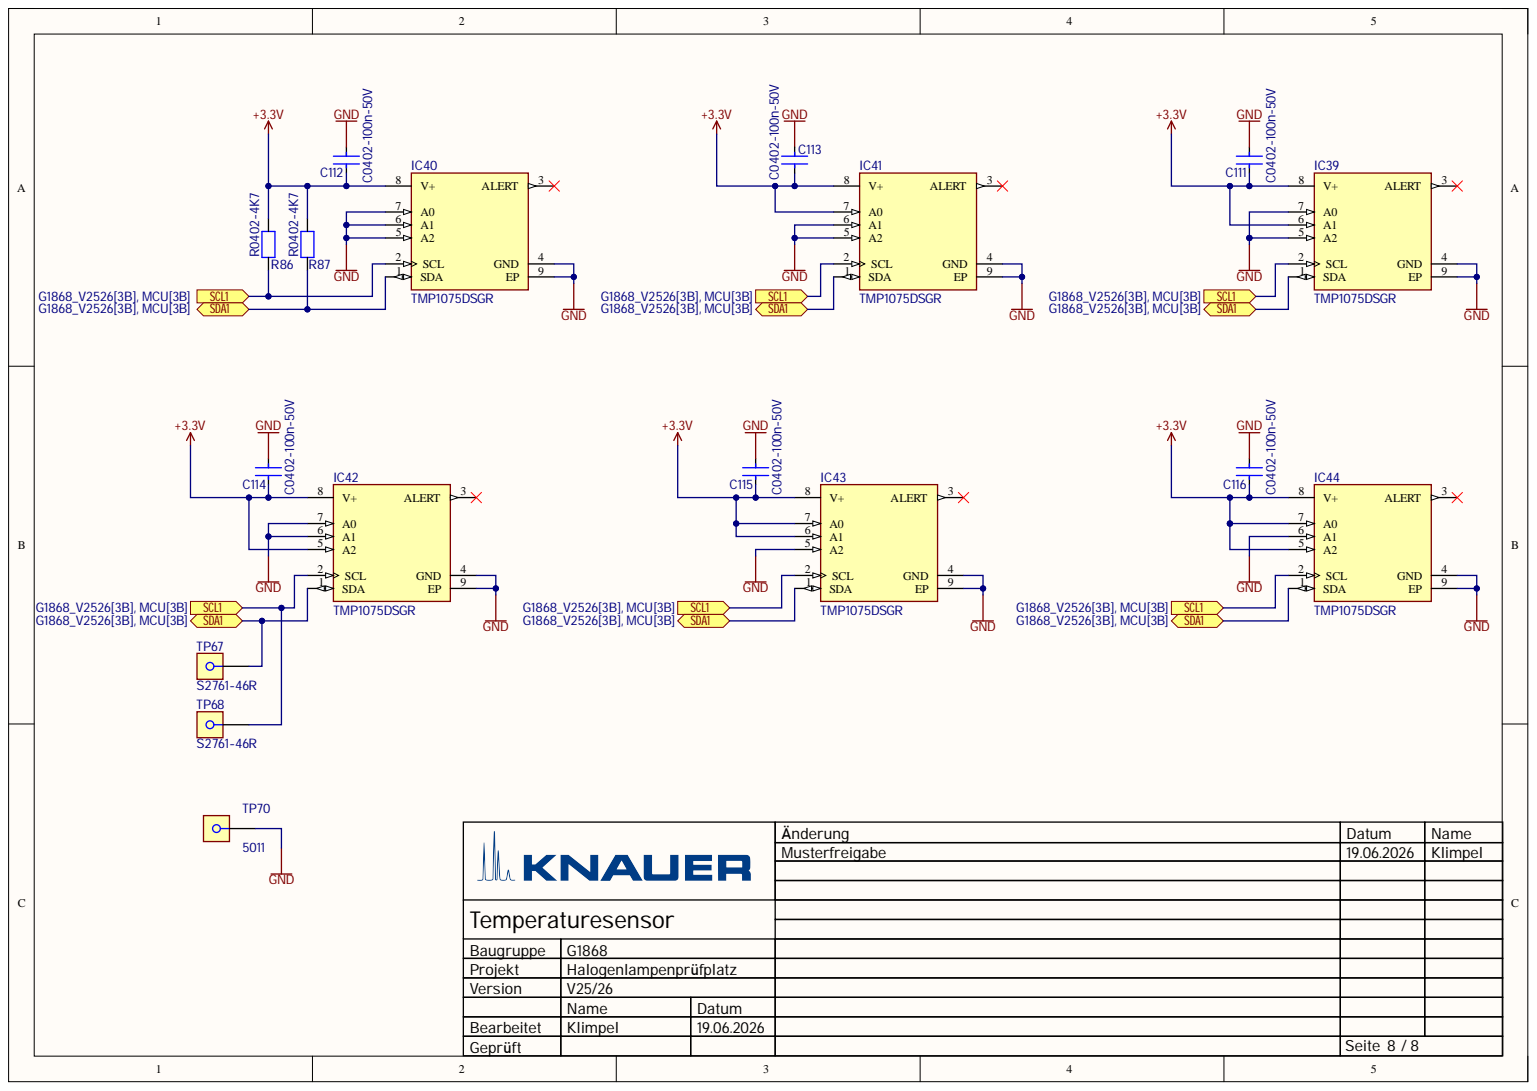
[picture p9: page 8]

Änderung | Datum | Name
Musterfreigabe | 19.06.2026 | Klimpel

Temperaturesensor

Baugruppe | G1868
Projekt | Halogenlampenprüfplatz
Version | V25/26

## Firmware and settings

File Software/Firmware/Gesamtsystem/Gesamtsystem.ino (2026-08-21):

#include <Wire.h>
#include <EEPROM.h>
#include <Adafruit_GFX.h>
#include <Adafruit_ILI9341.h>
#include <Fonts/FreeSansBold24pt7b.h>
#include <Fonts/FreeSansBold12pt7b.h>
#include <Fonts/FreeSansBold9pt7b.h>

// ================= DAC =================
#define DAC_ADDR 0x0F

const int numChannels = 10;
int enablePins[numChannels] = {0,1,2,3,4,5,6,7,8,9};
float channelVoltage[numChannels] = {0};

const float VREF = 5.0;
const uint16_t DAC_MAX = 65535;

// ================= FAN =================
// Fan1 = rechts (FanR), Fan2 = links (FanL)
const int pinPWM = 33;
const int tach1 = 28;   // Fan1 = rechts
const int tach2 = 29;   // Fan2 = links

volatile unsigned long pulsesFan1 = 0;
volatile unsigned long pulsesFan2 = 0;

volatile unsigned long lastPulseTime1 = 0;
volatile unsigned long lastPulseTime2 = 0;

unsigned long lastStatusTime = 0;   // gemeinsamer Takt fuer die Statusausgabe (1 s)

// Luefter-Kennlinie: linear 0V -> 0%, ab 5V -> 100% (auch bei spaeteren 7V)
const float FAN_FULL_VOLT = 5.0;   // Spannung, ab der 100% erreicht sind
const int   FAN_MIN_COOL  = 30;    // Mindestdrehzahl in der Abkuehlphase [%]
bool fanFloorActive = false;       // 30%-Floor erst nach dem ersten Hochlauf aktiv

// Luefter-Nachlauf: nach Testende/Stop noch ~2 min auf 30% (Restwaerme abfuehren)
const int           FAN_RUNOUT_PCT = 30;
const unsigned long FAN_RUNOUT_MS  = 120000UL;   // 2 Minuten
unsigned long       fanRunoutUntil = 0;

// ================= TEMP =================
// T1..T6 mit fest verdrahteten I2C-Adressen (aus den Binaeradressen umgerechnet)
// T1=1001011=0x4B, T2=1001101=0x4D, T3=1001000=0x48,
// T4=1001010=0x4A, T5=1001100=0x4C, T6=1001001=0x49
uint8_t sensors[] = {0x4B, 0x4D, 0x48, 0x4A, 0x4C, 0x49};
const int numSensors = 6;

// ================= STROM- & SPANNUNGSMESSUNG =================
// Beide Multiplexer (CD74HC4067) teilen sich die Steuerleitungen S0..S3 (parallel).
const int muxS0   = 23;   // S0
const int muxS1   = 22;   // S1
const int muxS2   = 21;   // S2
const int muxS3   = 20;   // S3

// Strom:    Shunt 75 mOhm -> INA190A1 (Gain 25 V/V) -> Mux 1 -> Pin 14
const int muxSigI = 14;   // Ausgang Strom-Mux
// Spannung: Teiler Rtop=11,3k / Rbot=10k -> Spannungsfolger TLV9001 -> Mux 2 -> Pin 15
const int muxSigU = 15;   // Ausgang Spannungs-Mux

const int   numCurrent = 10;        // I1..I10 = Mux-Kanal 0..9
const int   numVoltage = 10;        // U1..U10 = Mux-Kanal 0..9

const float SHUNT_OHM  = 0.075;     // 75 mOhm
const float INA_GAIN   = 25.0;      // INA190A1 = 25 V/V

const float VDIV_RTOP   = 11300.0;  // Spannungsteiler oben [Ohm]
const float VDIV_RBOT   = 10000.0;  // Spannungsteiler unten [Ohm]
const float VDIV_FACTOR = (VDIV_RTOP + VDIV_RBOT) / VDIV_RBOT;  // = 2,13

const float ADC_REF    = 3.3;       // Teensy 4.1 ADC-Referenz
const int   ADC_MAX    = 4095;      // 12-bit Aufloesung

// ================= SPANNUNGSREGELUNG =================
// Jeder Kanal wird anhand der gemessenen Ausgangsspannung auf den Sollwert nachgeregelt.
const float REG_GAIN     = 0.4;     // Regelverstaerkung (sanft -> kein Ueberschwingen)
const float REG_DEADBAND = 0.004;   // V: > ADC-Aufloesung (~1,7 mV), sonst Pendeln
const float REG_STEP_MAX = 0.01;    // max. Korrektur pro Zyklus [V] (gegen Ausreisser)
const float TRIM_LIMIT   = 2.0;     // max. Korrektur am DAC-Wert [V]

// Gelernte Korrektur je Kanal. Gilt NUR im Haltepunkt (volle Spannung) - waehrend der
// Rampen wird sie absichtlich nicht angewendet (siehe setVoutRamp), und bei jedem
// Teststart wird sie verworfen (siehe startTest).
float vdacTrim[numChannels]    = {0};
float voltageMeas[numChannels] = {0};  // zuletzt gemessene Ausgangsspannung je Kanal

// Letzte Messwerte (fuer GUI-Abfragen, DATA-Stream, Logging)
float lastCurrent[numChannels] = {0};
float lastTemp[numSensors]     = {0};
int   lastRpmR = 0, lastRpmL = 0;
// Drehzahl-Messfenster bewusst ~1 s, UNABHAENGIG vom (schnellen) Stream-Intervall.
// Bei 100 ms Stream fallen bei ~2000 U/min nur 6-7 Tacho-Pulse an -> ein Puls
// mehr/weniger = +-300 U/min "Springen". Ueber ~1 s werden ~66 Pulse gezaehlt
// -> Aufloesung ~30 U/min, die Anzeige bleibt ruhig.
unsigned long lastRpmTime = 0;
const unsigned long RPM_WINDOW_MS = 1000;
unsigned long statusMs = 1000;   // Mess-/Ausgabe-Intervall [ms]
bool  streamOn = true;           // automatische DATA-Ausgabe an die GUI
bool  guiConnected = false;      // GUI/Software steuert das Geraet -> anderer Startbildschirm

// Zweipunkt-Kalibrierung der Spannungsmessung: U_korr = vCalA * U_roh + vCalB
// vCalA: 2-Punkt (1V/5V). vCalB am 25.06.2026 bei 5V UNTER LAST feinabgeglichen
// (vCalB += V_Lampe - U), damit die Messung am Arbeitspunkt exakt der Lampenspannung entspricht.
//                          K1       K2        K3       K4        K5       K6       K7       K8       K9       K10
float vCalA[numChannels] = {0.98657, 0.99445,  0.99250, 0.99473,  0.99126, 0.98780, 0.98315, 0.98827, 0.98801, 0.98726};
float vCalB[numChannels] = {0.02990,-0.00639,  0.00362,-0.00466,  0.00826, 0.02613, 0.05216, 0.02710, 0.02621, 0.03221};

bool holdMode = false;   // Kalibrier-/Halte-Modus: Test + Regelung pausiert

// ================= AUSGANGS-KALIBRIERUNG (Vorsteuerung) =================
// Pro Kanal: vdac = dacM[i] * Vout_soll + dacB[i]  (hardcoded).
// Damit trifft die reine Vorsteuerung (open-loop) bereits den Sollwert -> keine Regelung noetig.
// dacB am 25.06.2026 per 'dac'-Befehl direkt am Multimeter auf echte 5,00 V abgeglichen.
// dacM (Steigung, fuer die Rampe) stammt aus der 2-Punkt-Charakterisierung.
float dacM[numChannels] = {-0.71530,-0.71947,-0.71494,-0.71584,-0.71494,-0.71530,-0.71494,-0.71620,-0.71711,-0.71729};
float dacB[numChannels] = { 5.03150, 5.01235, 5.01270, 5.00420, 5.04170, 4.99550, 5.00970, 5.02500, 5.01755, 5.02345};

// Ausgangs-Feinkalibrierung (per GUI): korrigiert den Sollwert VOR der Vorsteuerung,
// damit die real anliegende Spannung dem eingestellten Sollwert entspricht.
//   Vout_korr = outCalM[i] * Vout_soll + outCalB[i]   (Standard 1 / 0 = keine Aenderung)
// Wird per Befehl CALSET gesetzt und mit CALSAVE dauerhaft im EEPROM abgelegt.
float outCalM[numChannels] = {1,1,1,1,1,1,1,1,1,1};
float outCalB[numChannels] = {0,0,0,0,0,0,0,0,0,0};
const uint32_t CAL_MAGIC = 0x57303643UL;   // 'W06C' -> gueltige EEPROM-Kalibrierung

bool useRegulation = true;    // Closed-loop-Nachregelung AN: kompensiert Lastabfall + Lampenunterschiede

// ================= TASTER + LED =================
const int pinRed    = 36;
const int pinGreen  = 37;
const int pinBlue   = 38;
const int pinButton = 35;

bool lastButton = LOW;   // INPUT_PULLDOWN -> Ruhezustand LOW, gedrueckt HIGH

// ================= TEST-ABLAUF =================
// IDLE   = bereit, LED weiss
// RUNNING= Test laeuft, LED blau
// DONE   = Test fertig, LED gruen
enum TestState { TEST_IDLE, TEST_RUNNING, TEST_DONE };
TestState testState = TEST_IDLE;

float testVoltage = 5.0;       // globale Soll-Spannung im Test (0..7 V, Vorgabe)
// Soll-Spannung PRO KANAL im Test (Vorgabe 5 V; per 'TESTVCH' einzeln setzbar)
float testVoltageCh[numChannels] = {5,5,5,5,5,5,5,5,5,5};
int   numCycles   = 10;        // Anzahl Zyklen pro Lampe (einstellbar)
const float MAX_VOUT = 7.0;    // erlaubte Maximalspannung

// --- Zeiten ---
const unsigned long STAGGER_MS = 1000;   // Zeitversatz zwischen den Slots

// Zeiten je Modus (Eval = schnell zum Testen, Real = echter Pruefzyklus):
// Rampe (Vout 0<->5V) + An-Zeit (volle Spannung) + Rampe runter + Aus-/Abkuehlzeit (0 V)
// Presets je Modus
const unsigned long RAMP_MS_EVAL = 2000;          // 2 s
const unsigned long ON_MS_EVAL   = 5000;          // 5 s
const unsigned long OFF_MS_EVAL  = 2000;          // 2 s
const unsigned long RAMP_MS_REAL = 1UL*60*1000;   // 1 min
const unsigned long ON_MS_REAL   = 30UL*60*1000;  // 30 min
const unsigned long OFF_MS_REAL  = 15UL*60*1000;  // 15 min

// Laufzeit-Parameter (per Serial/GUI einstellbar) - Start = Real
bool evalMode = false;
unsigned long rampDur = RAMP_MS_REAL;   // Rampe hoch = runter
unsigned long onDur   = ON_MS_REAL;     // Haltezeit bei Vollspannung
unsigned long offDur  = OFF_MS_REAL;    // Abkuehlzeit (0 V)

unsigned long rampMs() { return rampDur; }
unsigned long onMs()   { return onDur; }
unsigned long offMs()  { return offDur; }

// Phasen, die ein einzelner Slot durchlaeuft
enum SlotPhase { S_WAIT_START, S_RAMP_UP, S_HOLD, S_RAMP_DOWN, S_OFF, S_DONE };

struct Slot {
  SlotPhase     phase;
  uint8_t       cycle;        // aktueller Zyklus 0..numCycles
  unsigned long phaseStart;   // millis() beim Beginn der aktuellen Phase
};
Slot slots[numChannels];

unsigned long lastTestTick = 0;
const unsigned long TEST_TICK_MS = 20;   // Rampen-/DAC-Update alle 20 ms

// ================= DISPLAY (ILI9341) =================
#define TFT_CS   10
#define TFT_RST  40
#define TFT_DC   39
#define TFT_LITE 41
Adafruit_ILI9341 tft = Adafruit_ILI9341(TFT_CS, TFT_DC, TFT_RST);

#define KNAUER_BLUE 0x19F1   // Markenblau (Navy/Royal, RGB565)

// Bildschirm-Zustaende
enum Screen { SCR_LOGO, SCR_START, SCR_TEST };
Screen screen = SCR_LOGO;
unsigned long screenStart = 0;
const unsigned long LOGO_MS = 3000;   // Logo 3 s anzeigen

// Tabellen-Geometrie
const int TBL_X = 10, TBL_Y = 10, TBL_W = 300, TBL_H = 221;
const int TBL_ROWS = 6, TBL_COLS = 2;
const int TBL_ROWH = TBL_H / TBL_ROWS;   // 36
const int TBL_COLW = TBL_W / TBL_COLS;   // 150

// Fehlererkennung + Zeichen-Cache (nur bei Aenderung neu zeichnen)
bool      lampDefect[numChannels]   = {false};   // Lampe defekt (gelatcht, bis Testende)
uint16_t  lampDrawnColor[numChannels];           // zuletzt gezeichnete Farbe je Lampe
const float CURRENT_MIN = 0.5;   // < 500 mA im Haltepunkt -> Lampe durchgebrannt

// Fortschrittsbalken (fliessend, zeitbasiert)
unsigned long testStartMs = 0;     // Startzeitpunkt des Tests
unsigned long testTotalMs = 1;     // erwartete Gesamtdauer des Tests
int           barLastPx   = 0;     // zuletzt gezeichnete Balkenbreite [px]
unsigned long lastBarUpdate = 0;   // Throttle fuer die Balken-Animation

// ================= SERIAL =================
String inputString = "";

// ================= SETUP =================
void setup() {
  Serial.begin(115200);

  calLoadEEPROM();   // gespeicherte Ausgangs-Feinkalibrierung laden (falls vorhanden)

  Wire.begin();
  Wire1.begin();

  for (int i=0;i<numChannels;i++){
    pinMode(enablePins[i], OUTPUT);
    digitalWrite(enablePins[i], LOW);       // Buck-Wandler aus
    channelVoltage[i] = 0;
    setDAC(i, voutToVdac(0));                // DAC in definierten 0-V-Zustand (Enable bleibt LOW)
  }

  pinMode(pinPWM, OUTPUT);
  analogWriteResolution(8);
  analogWriteFrequency(pinPWM, 25000);
  analogWrite(pinPWM, 0);

  pinMode(tach1, INPUT_PULLUP);
  pinMode(tach2, INPUT_PULLUP);

  attachInterrupt(digitalPinToInterrupt(tach1), tachISR1, RISING);
  attachInterrupt(digitalPinToInterrupt(tach2), tachISR2, RISING);
  lastRpmTime = millis();   // Startzeitpunkt fuer das ~1-s-Drehzahlfenster

  // Multiplexer / Strommessung
  pinMode(muxS0, OUTPUT);
  pinMode(muxS1, OUTPUT);
  pinMode(muxS2, OUTPUT);
  pinMode(muxS3, OUTPUT);
  selectMuxChannel(0);
  analogReadResolution(12);
  analogReadAveraging(32);   // Hardware-Mittelung gegen ADC-Rauschen

  // Taster + LED
  pinMode(pinRed,   OUTPUT);
  pinMode(pinGreen, OUTPUT);
  pinMode(pinBlue,  OUTPUT);
  pinMode(pinButton, INPUT_PULLDOWN);

  setLED(TEST_IDLE);   // Start: weiss

  // Display
  pinMode(TFT_LITE, OUTPUT);
  digitalWrite(TFT_LITE, HIGH);    // Hintergrundbeleuchtung an
  tft.begin();
  tft.setRotation(1);
  tft.setTextSize(1);
  drawLogo();                      // Knauer-Logo fuer 2 s
  screen = SCR_LOGO;
  screenStart = millis();

  Serial.println("W0609 Halogenlampentest bereit. 'HELP' fuer Befehle.");
}

// ================= LOOP =================
void loop() {
  handleSerial();
  handleButton();
  updateTest();
  updateFanControl();
  updateStatus();
  updateDisplay();
  updateLED();     // LED-Farbe/Blinken (inkl. Kalibriermodus = Magenta)
}

// ================= LED =================
void setLED(TestState s) {
  bool r = false, g = false, b = false;
  switch (s) {
    case TEST_IDLE:    r = true; g = true; b = true; break; // weiss
    case TEST_RUNNING: b = true;                     break; // blau
    case TEST_DONE:    g = true;                     break; // gruen
  }
  digitalWrite(pinRed,   r ? HIGH : LOW);
  digitalWrite(pinGreen, g ? HIGH : LOW);
  digitalWrite(pinBlue,  b ? HIGH : LOW);
}

// LED-Anzeige inkl. Kalibriermodus. Wird in jedem loop() aufgerufen (fuer das Blinken).
// Im Kalibriermodus (holdMode): GELB (Rot+Gruen).
//   - solide, solange keine Spannung anliegt (0 V)  -> "Kalibriermodus aktiv, ungefaehrlich"
//   - blinkend, sobald eine Kalibrierspannung anliegt (>0 V) -> "Achtung, Spannung live"
// Sonst: normale Zustandsfarbe (weiss/blau/gruen) ueber setLED().
unsigned long      ledBlinkLast = 0;
bool               ledBlinkOn   = true;
const unsigned long LED_BLINK_MS = 400;   // Blink-Takt in ms

void updateLED() {
  if (holdMode) {
    bool live = false;
    for (int i = 0; i < numChannels; i++)
      if (channelVoltage[i] > 0.01f) { live = true; break; }
    bool on = true;
    if (live) {
      unsigned long now = millis();
      if (now - ledBlinkLast >= LED_BLINK_MS) { ledBlinkLast = now; ledBlinkOn = !ledBlinkOn; }
      on = ledBlinkOn;
    }
    digitalWrite(pinRed,   on ? HIGH : LOW);   // Gelb = Rot + Grün
    digitalWrite(pinGreen, on ? HIGH : LOW);
    digitalWrite(pinBlue,  LOW);
  } else {
    setLED(testState);
  }
}

// ================= TASTER =================
void handleButton() {
  bool b = digitalRead(pinButton);

  // steigende Flanke (LOW -> HIGH) = Taster gedrueckt
  if (lastButton == LOW && b == HIGH) {
    delay(30);  // kleines Entprellen

    if (testState == TEST_IDLE) {
      startTest();
    } else if (testState == TEST_DONE) {
      stopTest();   // zurueck zu IDLE / bereit fuer naechsten Lauf
    }
    // waehrend TEST_RUNNING: Tasterdruck wird ignoriert
  }

  lastButton = b;
}

// ================= TEST-STEUERUNG =================
void startTest() {
  unsigned long now = millis();
  holdMode = false;   // evtl. aktiven Kalibrier-/Halte-Modus sicher beenden
  for (int i=0;i<numChannels;i++){
    slots[i].phase      = S_WAIT_START;
    slots[i].cycle      = 0;
    slots[i].phaseStart = now;
    digitalWrite(enablePins[i], LOW);
    channelVoltage[i] = 0;
    vdacTrim[i] = 0;            // gelernte Korrektur verwerfen -> jeder Test startet gleich
    setDAC(i, voutToVdac(0));   // DAC vorinitialisieren (Enable noch LOW)
  }
  for (int i=0;i<numChannels;i++) lampDefect[i] = false;   // Fehler-Flags zuruecksetzen
  fanFloorActive = false;   // Luefter darf beim Start wieder von 0% hochlaufen
  testState = TEST_RUNNING;
  setLED(TEST_RUNNING);

  // erwartete Gesamtdauer fuer den fliessenden Fortschrittsbalken
  testStartMs = now;
  unsigned long cycleTotal = 2UL*rampMs() + onMs() + offMs();
  testTotalMs = (unsigned long)(numChannels - 1) * STAGGER_MS
              + (unsigned long)numCycles * cycleTotal;

  screen = SCR_TEST;        // Display auf Testansicht umschalten
  drawTestLayout();
  Serial.print("Test gestartet (");
  Serial.print(evalMode ? "Eval 5s/2s" : "Real 30min/15min");
  Serial.println(").");
}

void stopTest() {
  for (int i=0;i<numChannels;i++){
    digitalWrite(enablePins[i], LOW);
    channelVoltage[i] = 0;
    slots[i].phase = S_DONE;
  }
  fanRunoutUntil = millis() + FAN_RUNOUT_MS;   // Luefter laufen ~2 min nach
  fanFloorActive = false;
  holdMode = false;
  testState = TEST_IDLE;
  setLED(TEST_IDLE);
  screen = SCR_START;       // zurueck zum Startbildschirm
  drawIdle();
  Serial.println("Test gestoppt / zurueckgesetzt.");
}

// ================= KALIBRIER-/HALTE-MODUS =================
// Alle Kanaele open-loop auf eine feste Spannung legen (zum Kalibrieren / Messen).
void startHold(float v) {
  holdMode = true;
  testState = TEST_IDLE;
  fanFloorActive = false;

  for (int i = 0; i < numChannels; i++) {
    slots[i].phase = S_DONE;          // Test-Statemachine stilllegen
    if (v <= 0.0) {
      digitalWrite(enablePins[i], LOW);
      channelVoltage[i] = 0;
      setDAC(i, 0);
    } else {
      digitalWrite(enablePins[i], HIGH);
      channelVoltage[i] = v;
      setDAC(i, voutToVdac(v));        // reine Vorsteuerung, kein Trim, keine Regelung
    }
  }

  setLED(TEST_IDLE);
  Serial.print("HOLD-Modus: alle Kanaele open-loop auf ");
  Serial.print(v);
  Serial.println(" V (Regelung pausiert). 'raw' zum Auslesen, 'stop' zum Beenden.");
}

// Alle Kanaele auf eine Spannung setzen und dabei (kalibriert) nachregeln.
void setAllRegulated(float v) {
  holdMode = false;
  testState = TEST_IDLE;
  fanFloorActive = false;

  for (int i = 0; i < numChannels; i++) {
    slots[i].phase = S_DONE;          // Test-Statemachine inaktiv
    if (v <= 0.0) {
      digitalWrite(enablePins[i], LOW);
      channelVoltage[i] = 0;
      setDAC(i, 0);
    } else {
      digitalWrite(enablePins[i], HIGH);
      setVout(i, v);                  // Vorsteuerung + Trim; regulate() zieht nach
    }
  }

  setLED(TEST_IDLE);
  Serial.print("Alle Kanaele auf ");
  Serial.print(v);
  Serial.println(" V (kalibrierte Vorsteuerung).");
}

// DAC eines einzelnen Kanals DIREKT setzen (ohne Kennlinie/Kalibrierung/Regelung).
// Zum manuellen Einstellen, bis das Multimeter genau 5,00 V zeigt.
// ch1 = 1-basiert. Hinweis: hoeherer DAC-Wert -> kleinere Ausgangsspannung (invertierend).
void setDacDirect(int ch1, float vdac) {
  int ch = ch1 - 1;
  if (ch < 0 || ch >= numChannels) {
    Serial.println("Kanal muss 1..10 sein.");
    return;
  }
  if (vdac < 0.0) vdac = 0.0;
  if (vdac > 5.0) vdac = 5.0;

  holdMode = true;          // Test + Regelung pausieren
  testState = TEST_IDLE;

  // alle anderen Kanaele ausschalten, nur den gemessenen aktiv
  for (int i = 0; i < numChannels; i++) {
    slots[i].phase = S_DONE;
    if (i != ch) {
      digitalWrite(enablePins[i], LOW);
      channelVoltage[i] = 0;
      setDAC(i, 0);
    }
  }

  digitalWrite(enablePins[ch], HIGH);
  channelVoltage[ch] = 5.0;   // nur fuer die Luefterregelung (Kuehlung an)
  setDAC(ch, vdac);           // DAC direkt, ungefiltert

  setLED(TEST_IDLE);
  Serial.print("Kanal ");
  Serial.print(ch1);
  Serial.print(": DAC = ");
  Serial.print(vdac, 3);
  Serial.println(" V (direkt). Multimeter messen; hoeher = weniger Vout. 'stop' beendet.");
}

// Rohe Spannungsmesswerte aller Kanaele ausgeben (fuer die Kalibrierung)
void printRaw() {
  Serial.print("RAW U: ");
  for (int i = 0; i < numVoltage; i++) {
    Serial.print("U");
    Serial.print(i + 1);
    Serial.print("=");
    Serial.print(readVoltageRaw(i), 3);
    Serial.print(" V  ");
  }
  Serial.println();
}

void updateTest() {
  if (testState != TEST_RUNNING) return;

  unsigned long now = millis();
  if (now - lastTestTick < TEST_TICK_MS) return;
  lastTestTick = now;

  bool allDone = true;

  for (int i=0;i<numChannels;i++){
    Slot &s = slots[i];
    if (s.phase == S_DONE) continue;
    allDone = false;

    unsigned long elapsed = now - s.phaseStart;

    switch (s.phase) {

      case S_WAIT_START:
        // Anfangs-Zeitversatz: Slot i wartet i * STAGGER_MS
        if (elapsed >= (unsigned long)i * STAGGER_MS) {
          digitalWrite(enablePins[i], HIGH);
          s.phase = S_RAMP_UP;
          s.phaseStart = now;
        }
        break;

      case S_RAMP_UP: {
        if (elapsed >= rampMs()) {
          setVout(i, testVoltageCh[i]);
          s.phase = S_HOLD;
          s.phaseStart = now;
          fanFloorActive = true;   // ab jetzt Mindestdrehzahl in Abkuehlphasen
        } else {
          float v = testVoltageCh[i] * (float)elapsed / (float)rampMs();
          setVoutRamp(i, v);          // ohne gelernte Korrektur -> Rampe startet bei 0 V
        }
        break;
      }

      case S_HOLD:
        // volle Spannung halten (DAC bleibt unveraendert)
        if (elapsed >= onMs()) {
          s.phase = S_RAMP_DOWN;
          s.phaseStart = now;
        }
        break;

      case S_RAMP_DOWN: {
        if (elapsed >= rampMs()) {
          setVoutRamp(i, 0);          // ohne Korrektur -> wirklich 0 V, kein Rest-Offset
          digitalWrite(enablePins[i], LOW);
          if (lampDefect[i]) {
            s.phase = S_DONE;      // defekt -> stillgelegt, keine weiteren Zyklen
          } else {
            s.phase = S_OFF;
            s.phaseStart = now;
          }
        } else {
          float v = testVoltageCh[i] * (1.0 - (float)elapsed / (float)rampMs());
          setVoutRamp(i, v);          // ohne gelernte Korrektur (gilt nur im Haltepunkt)
        }
        break;
      }

      case S_OFF:
        if (elapsed >= offMs()) {
          s.cycle++;
          if (s.cycle >= numCycles) {
            s.phase = S_DONE;
          } else {
            digitalWrite(enablePins[i], HIGH);
            s.phase = S_RAMP_UP;
            s.phaseStart = now;
          }
        }
        break;

      default:
        break;
    }
  }

  if (allDone) {
    testState = TEST_DONE;
    setLED(TEST_DONE);
    fanRunoutUntil = millis() + FAN_RUNOUT_MS;   // Luefter-Nachlauf nach Testende
    Serial.println("EVENT TESTDONE");
  }
}

// Globale Nenn-Kennlinie (nur fuer Kalibrier-/Hold-Modus): Vout -> DAC-Spannung
float voutToVdac(float vout) {
  float vdac = (7.03 - vout) / 1.41;
  if (vdac < 0.0) vdac = 0.0;
  if (vdac > 5.0) vdac = 5.0;
  return vdac;
}

// Reine (unkorrigierte) Vorsteuerung: Vout -> DAC-Spannung, ohne Ausgangs-Feinkalibrierung.
// Wird beim Kalibrier-Messen (CALOUT) genutzt, damit die Messung unabhaengig von outCal ist.
float voutToVdacChRaw(int channel, float vout) {
  float vdac = dacM[channel] * vout + dacB[channel]; 
  if (vdac < 0.0) vdac = 0.0;
  if (vdac > 5.0) vdac = 5.0;
  return vdac;
}
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

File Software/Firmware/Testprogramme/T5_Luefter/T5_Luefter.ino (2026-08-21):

/*
  T5 - Luefteransteuerung und Drehzahlrueckmeldung
  ================================================

  Erstellt: 01.07.2026 (Mi)

  Steuert beide Luefter ueber ein gemeinsames PWM-Signal und wertet die
  Tachosignale aus.

  PWM   : Pin 33, 25 kHz (ausserhalb des Hoerbereichs), 8 Bit
  Tacho : Pin 28 = Luefter rechts, Pin 29 = Luefter links
          zwei Impulse je Umdrehung, Auswertung ueber Interrupts

  Hinweis aus der Inbetriebnahme: Das PWM-Signal lag urspruenglich auf Pin 30.
  Dieser Pin ist beim Teensy 4.1 NICHT PWM-faehig, dort liegt nur ein
  statischer Pegel an und die Drehzahl laesst sich nicht regeln. Deshalb
  wurde auf den PWM-faehigen Pin 33 gewechselt.

  Ausgabe: serieller Monitor, 115200 Baud

  Befehle:
    <0-100>   Tastverhaeltnis in Prozent setzen
    K         Kennlinie automatisch aufnehmen (0 bis 100 % in 10er-Schritten)
    ?         Hilfe
*/

const int pinPWM = 33;
const int tach1  = 28;   // rechts
const int tach2  = 29;   // links

volatile unsigned long pulse1 = 0, pulse2 = 0;
void isr1() { pulse1++; }
void isr2() { pulse2++; }

int aktuellPWM = 0;

void setPWM(int prozent) {
  if (prozent < 0) prozent = 0;
  if (prozent > 100) prozent = 100;
  aktuellPWM = prozent;
  analogWrite(pinPWM, map(prozent, 0, 100, 0, 255));
}

// misst ueber ein Fenster von 1 s und liefert die Drehzahlen
void messeDrehzahl(int &rpmR, int &rpmL) {
  noInterrupts(); pulse1 = 0; pulse2 = 0; interrupts();
  unsigned long t0 = millis();
  delay(1000);
  unsigned long dt = millis() - t0;
  noInterrupts();
  unsigned long c1 = pulse1, c2 = pulse2;
  interrupts();
  rpmR = (int)((c1 / (dt / 1000.0)) * 60.0 / 2.0);   // 2 Impulse je Umdrehung
  rpmL = (int)((c2 / (dt / 1000.0)) * 60.0 / 2.0);
}

void setup() {
  Serial.begin(115200);
  while (!Serial && millis() < 3000) {}

  pinMode(pinPWM, OUTPUT);
  analogWriteResolution(8);
  analogWriteFrequency(pinPWM, 25000);
  analogWrite(pinPWM, 0);

  pinMode(tach1, INPUT_PULLUP);
  pinMode(tach2, INPUT_PULLUP);
  attachInterrupt(digitalPinToInterrupt(tach1), isr1, RISING);
  attachInterrupt(digitalPinToInterrupt(tach2), isr2, RISING);

  Serial.println();
  Serial.println("=== T5: Luefter und Drehzahlmessung ===");
  Serial.println("Befehle: <0-100> Prozent | K Kennlinie | ?");
}

void loop() {
  if (Serial.available()) {
    String s = Serial.readStringUntil('\n');
    s.trim(); s.toUpperCase();

    if (s == "?") {
      Serial.println("Zahl 0-100 = Tastverhaeltnis, K = Kennlinie aufnehmen");
    }
    else if (s == "K") {
      Serial.println();
      Serial.println("  PWM [%] | rechts [1/min] | links [1/min]");
      Serial.println("  --------+----------------+--------------");
      for (int p = 0; p <= 100; p += 10) {
        setPWM(p);
        delay(2000);                       // Luefter hochlaufen lassen
        int r, l; messeDrehzahl(r, l);
        Serial.print("   "); if (p < 100) Serial.print(" "); if (p < 10) Serial.print(" ");
        Serial.print(p);
        Serial.print("     |      "); Serial.print(r);
        Serial.print("       |     ");  Serial.println(l);
      }
      setPWM(0);
      Serial.println("  Kennlinie beendet, Luefter aus.");
    }
    else if (s.length() > 0 && isDigit(s.charAt(0))) {
      setPWM(s.toInt());
      Serial.print("PWM = "); Serial.print(aktuellPWM); Serial.println(" %");
    }
  }

  // laufende Anzeige
  static unsigned long last = 0;
  if (millis() - last > 2000) {
    last = millis();
    int r, l; messeDrehzahl(r, l);
    Serial.print("PWM "); Serial.print(aktuellPWM);
    Serial.print(" %   rechts "); Serial.print(r);
    Serial.print(" 1/min   links "); Serial.print(l); Serial.println(" 1/min");
    last = millis();
  }
}
